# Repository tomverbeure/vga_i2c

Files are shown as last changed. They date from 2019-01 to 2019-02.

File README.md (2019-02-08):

# VGA I2C GPIO + Atari 2600 Joystick Extender

**A detailed write-up about this project can be found [here](https://tomverbeure.github.io/2019/02/05/VGA-I2C-My-First-PCB.html).**

The [Pano Logic G1](https://github.com/tomverbeure/panologic) doesn't have an easy
way to add GPIOs or non-USB input devices.

If you want to control a game like PacMan with a joystick, you need to be creative.
One way to do that is by soldering some wires to connect unused VGA pins to the
FPGA as demonstrated by the [Pano Man](https://github.com/skiphansen/pano_man) project.

But only allow for a lot of buttons. The Pano Man README suggested connecting a
GPIO I2C expander to the I2C wires of the VGA cable.

This project does exactly that!

It's a VGA to VGA feedthru board that taps the I2C wires, adds an I2C GPIO expander, connects it
to 2 Atari 2600 joystick ports, 4 additional switches and 2 LEDs.

I shared the schematics of this board with Skip, the author of Pano Man, and he made a
version that supports this board!

The design is very simple and it was the perfect project to learn KiCAD and design and 
send out for production my first PCB.

The schematic:

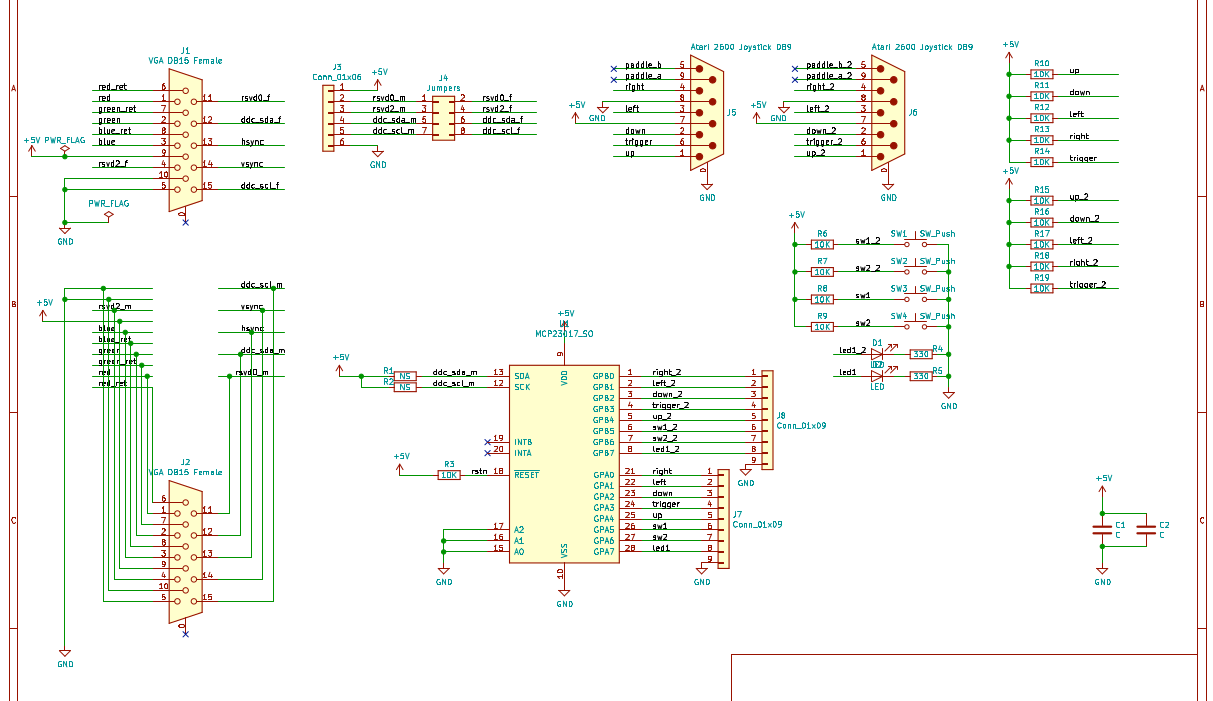
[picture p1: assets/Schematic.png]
Schematic


The PCB layout:

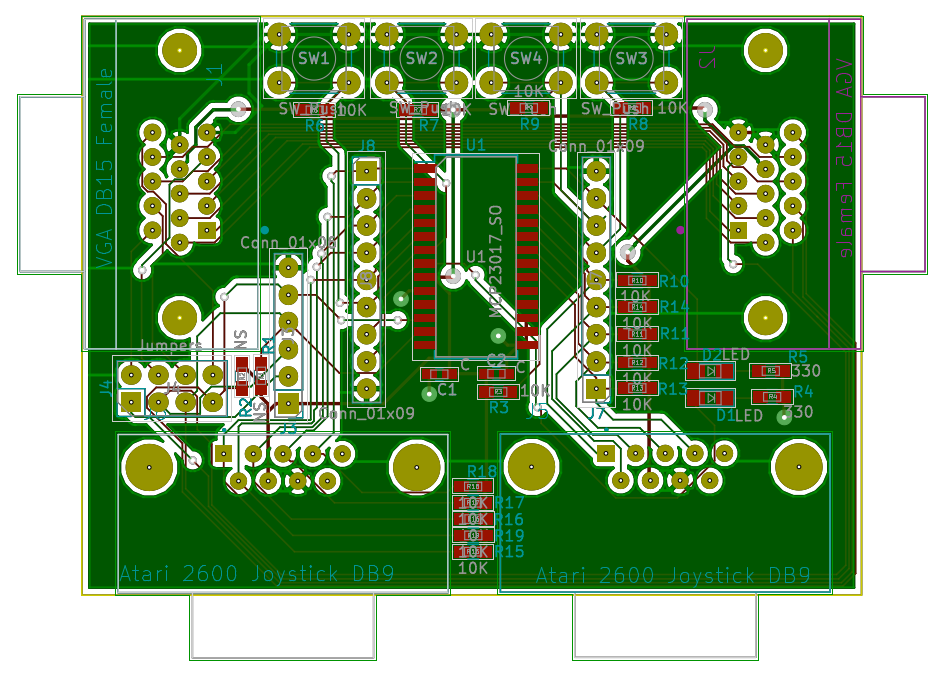
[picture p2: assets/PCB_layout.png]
PCB Layout


The result:

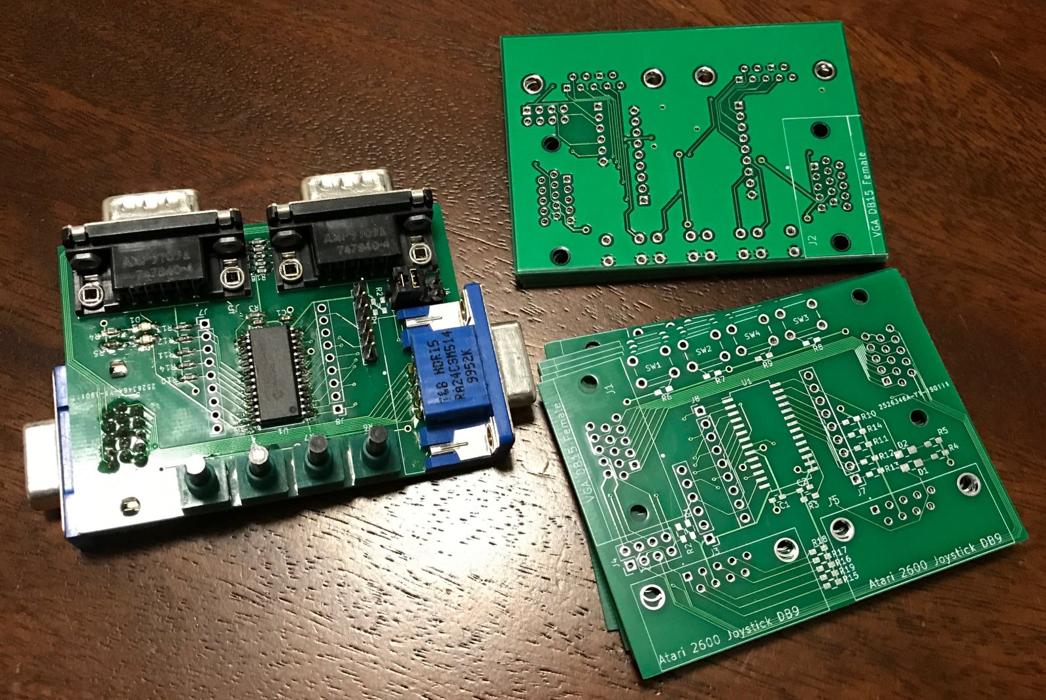
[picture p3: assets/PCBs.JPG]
PCBs


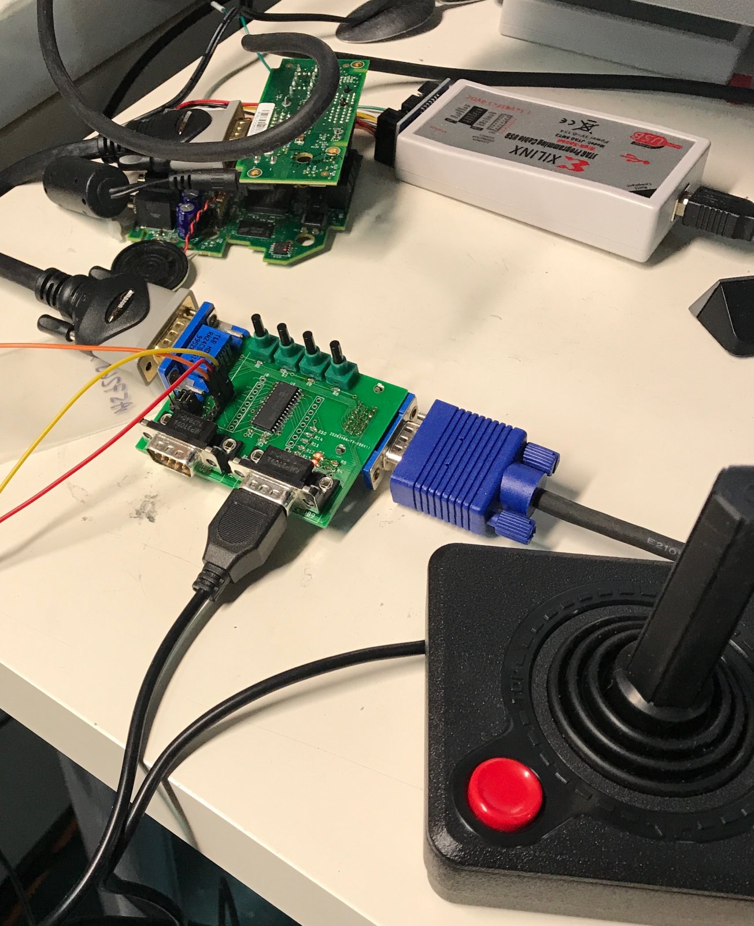
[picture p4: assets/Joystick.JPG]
Joystick


[Video](https://player.vimeo.com/video/315809161)

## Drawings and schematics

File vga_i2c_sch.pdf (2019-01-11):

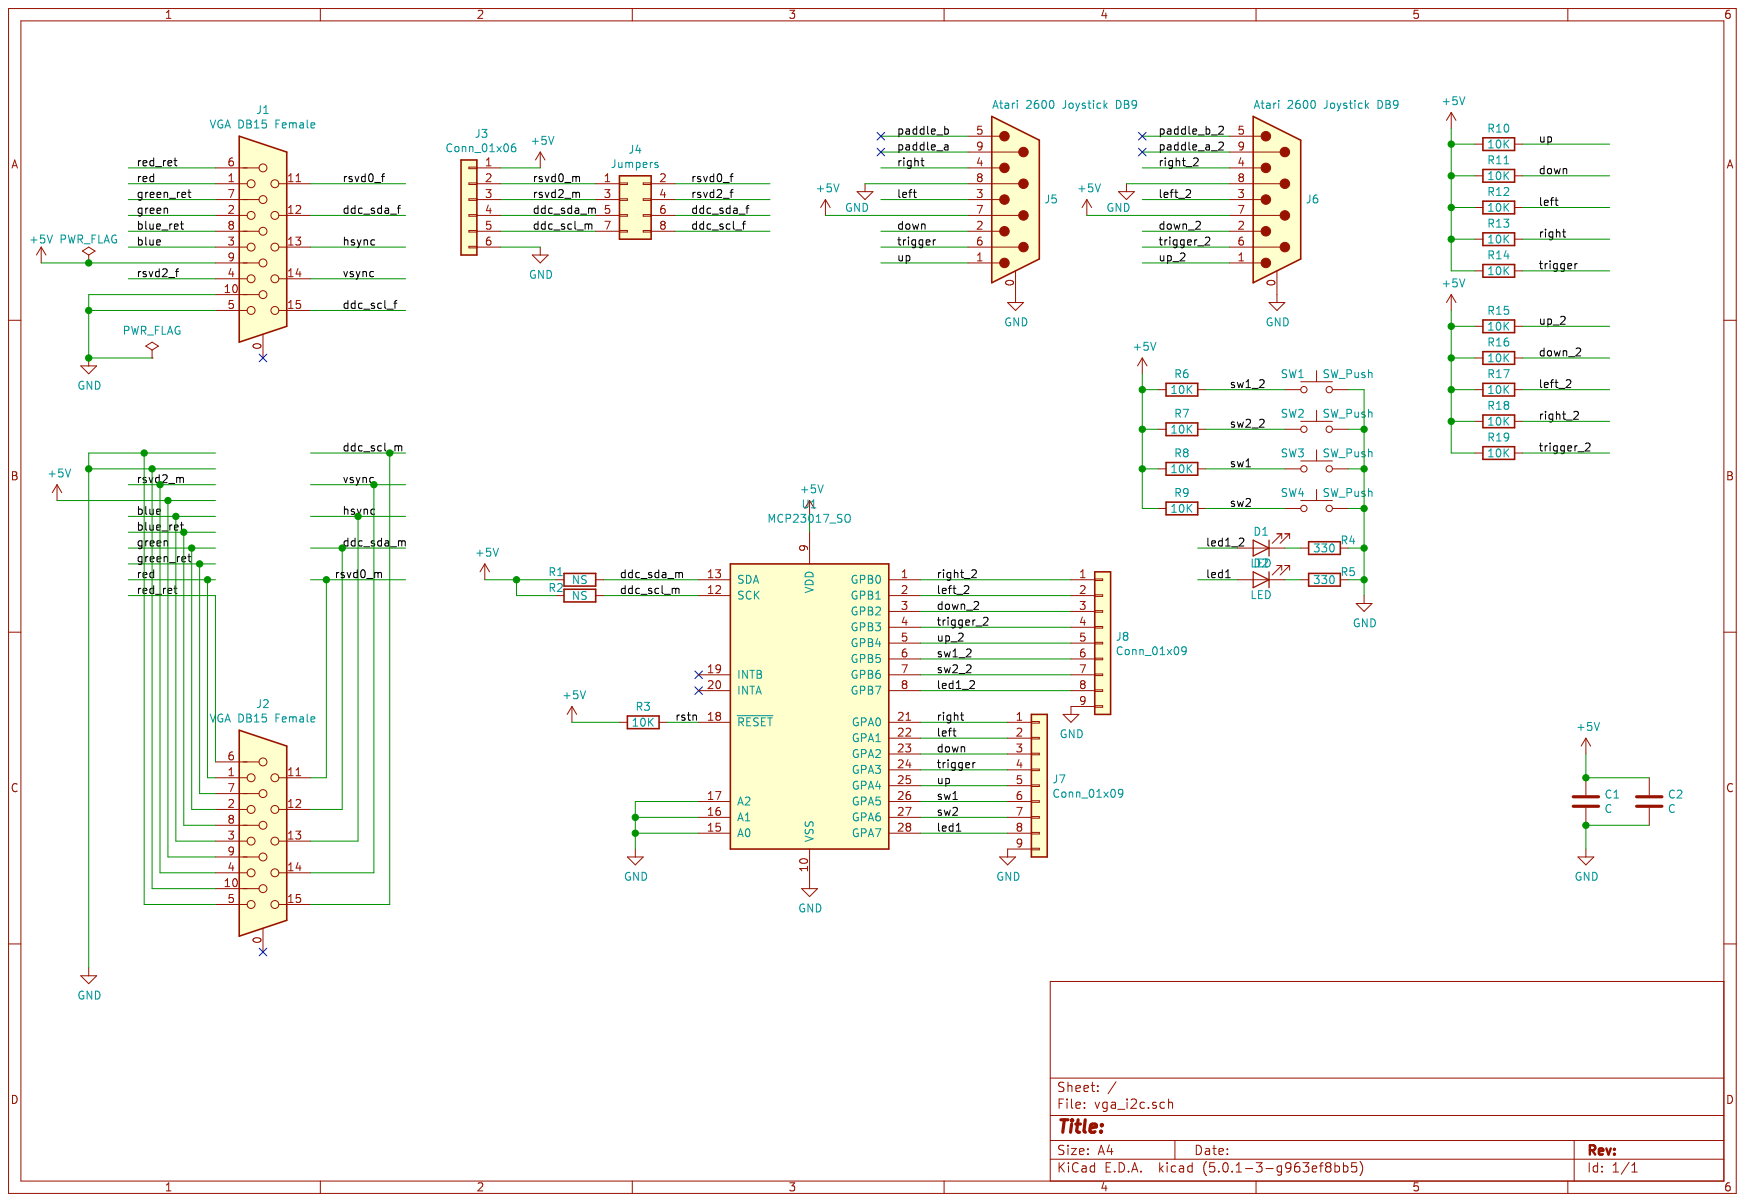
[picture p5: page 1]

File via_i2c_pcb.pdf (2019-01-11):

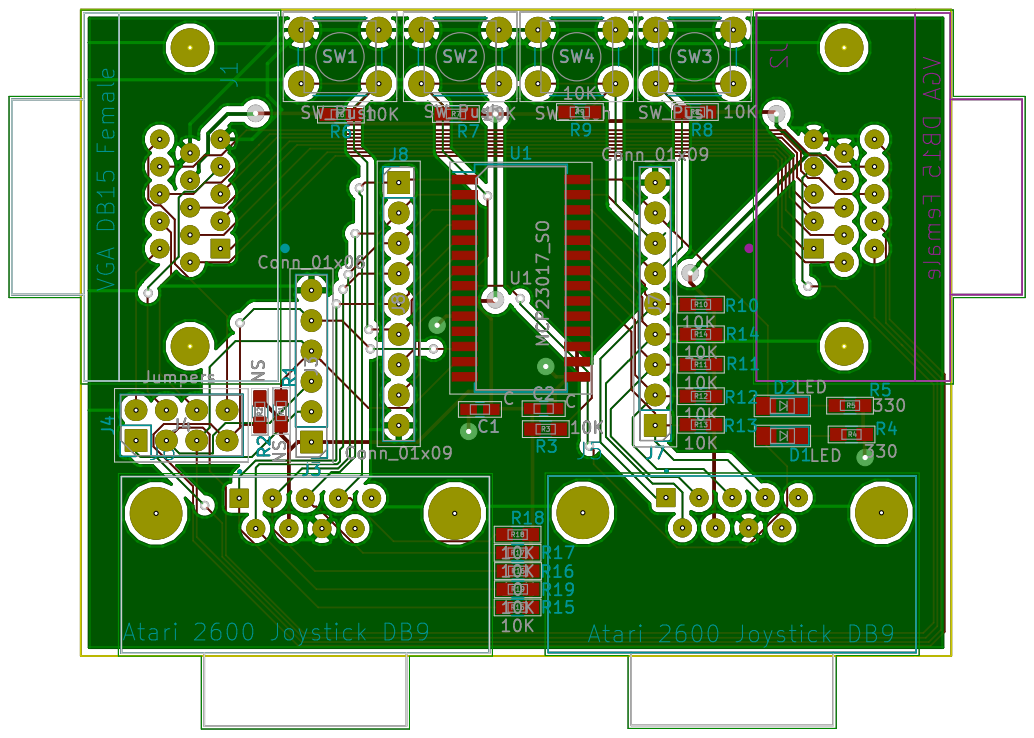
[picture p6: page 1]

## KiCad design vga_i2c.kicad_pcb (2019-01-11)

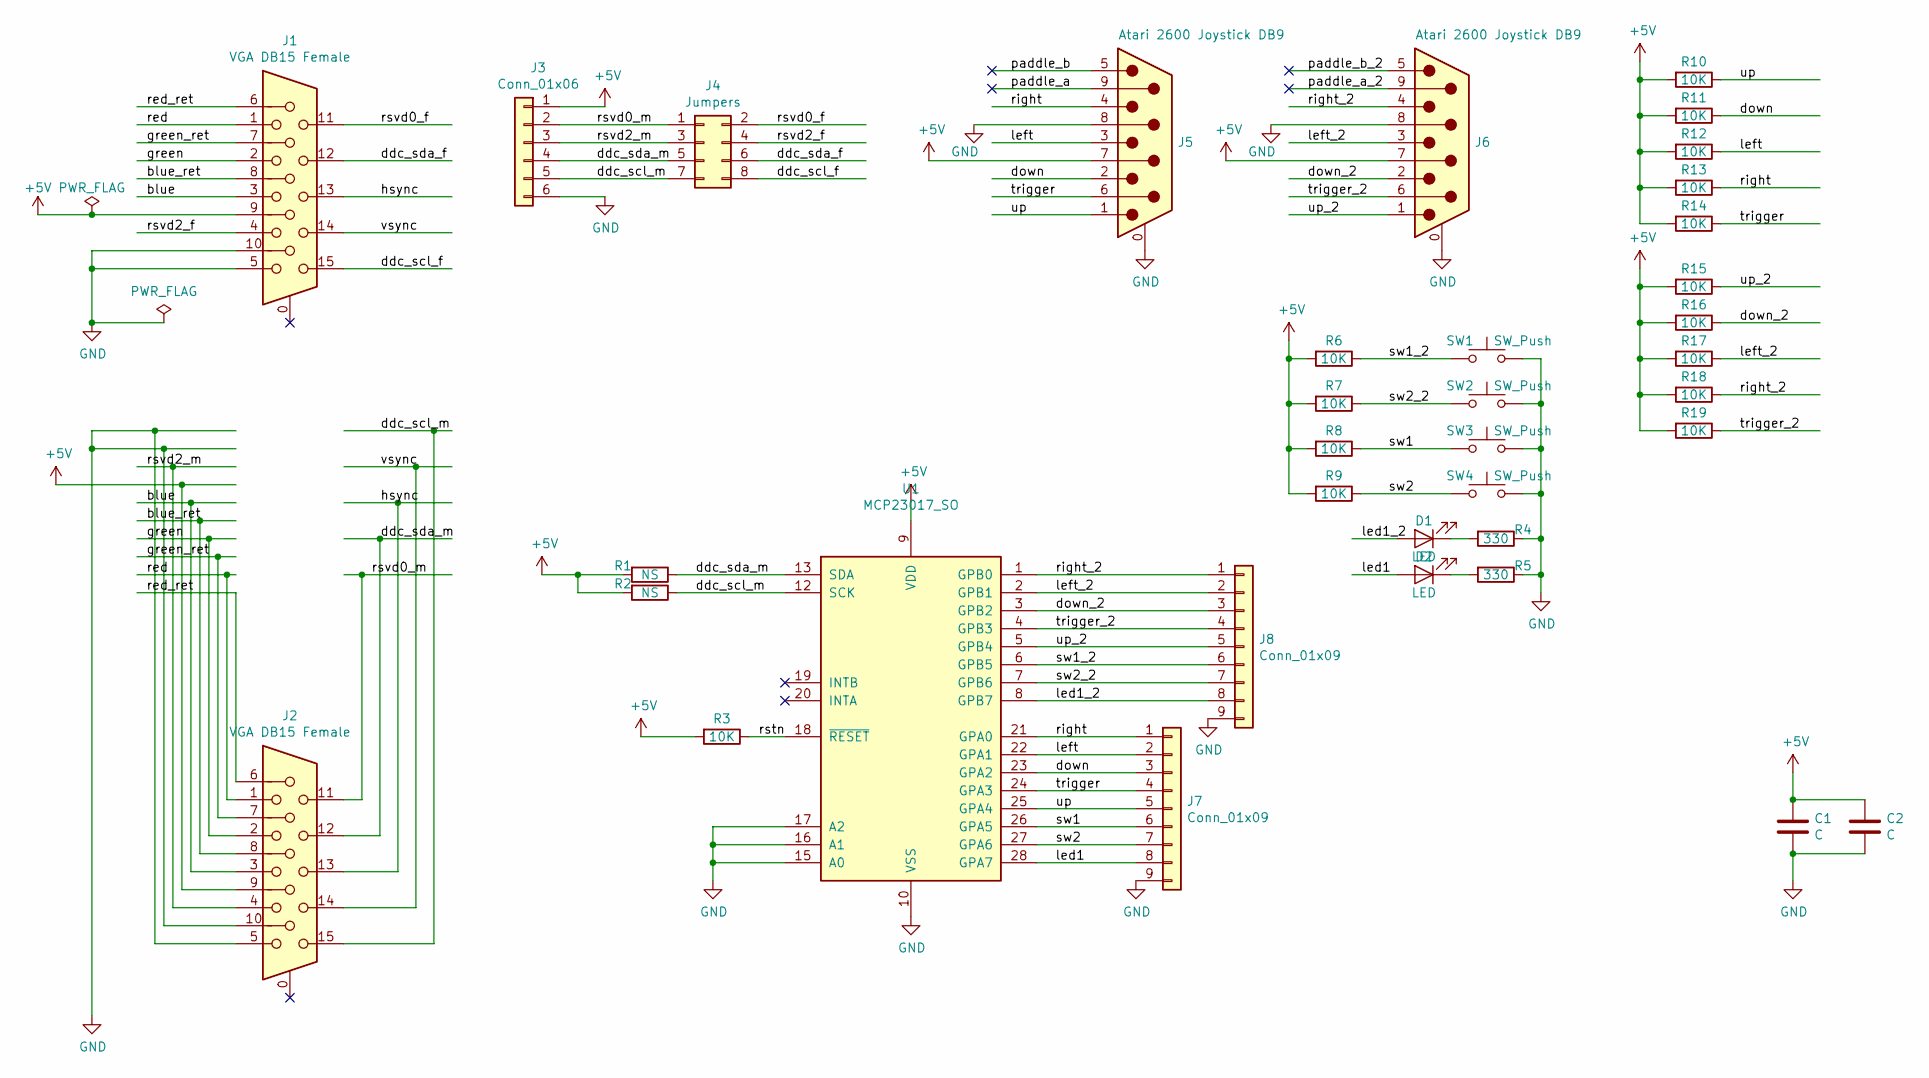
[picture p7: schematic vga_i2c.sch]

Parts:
C1, C2: C; C_0603_HandSoldering
D1, D2: LED; LED_0805_HandSoldering
J1, J2: VGA DB15 Female; NORCOMP_181-015-213R561
J3: Conn_01x06; Pin_Header_Straight_1x06_Pitch2.54mm
J4: Jumpers; Pin_Header_Straight_2x04_Pitch2.54mm
J5, J6: Atari 2600 Joystick DB9; TE_1-1634580-2
J7, J8: Conn_01x09; Pin_Header_Straight_1x09_Pitch2.54mm
R1, R2: NS; R_0603_HandSoldering
R3, R6, R7, R8, R9, R10, R11, R12, R13, R14, R15, R16, R17, R18, R19: 10K; R_0603_HandSoldering
R4, R5: 330; R_0603_HandSoldering
SW1, SW2, SW3, SW4: SW_Push; SW_PUSH_6mm
U1: MCP23017_SO; SOIC-28W_7.5x18.7mm_Pitch1.27mm

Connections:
+5V: C1.1, C2.1, J1.9, J2.9, J3.1, J5.7, J6.7, R1.2, R2.2, R3.2, R6.2, R7.2, R8.2, R9.2, R10.2, R11.2, R12.2, R13.2, R14.2, R15.2, R16.2, R17.2, R18.2, R19.2, U1.9 (VDD)
/blue: J1.3, J2.3
/blue_ret: J1.8, J2.8
/ddc_scl_f: J1.15, J4.8
/ddc_scl_m: J2.15, J3.5, J4.7, R2.1, U1.12 (SCK)
/ddc_sda_f: J1.12, J4.6
/ddc_sda_m: J2.12, J3.4, J4.5, R1.1, U1.13 (SDA)
/down: J5.2, J7.3, R11.1, U1.23 (GPA2)
/down_2: J6.2, J8.3, R16.1, U1.3 (GPB2)
/green: J1.2, J2.2
/green_ret: J1.7, J2.7
/hsync: J1.13, J2.13
/led1: D2.2 (A), J7.8, U1.28 (GPA7)
/led1_2: D1.2 (A), J8.8, U1.8 (GPB7)
/left: J5.3, J7.2, R12.1, U1.22 (GPA1)
/left_2: J6.3, J8.2, R17.1, U1.2 (GPB1)
/paddle_a: J5.9
/paddle_a_2: J6.9
/paddle_b: J5.5
/paddle_b_2: J6.5
/red: J1.1, J2.1
/red_ret: J1.6, J2.6
/right: J5.4, J7.1, R13.1, U1.21 (GPA0)
/right_2: J6.4, J8.1, R18.1, U1.1 (GPB0)
/rstn: R3.1, U1.18 (~RESET~)
/rsvd0_f: J1.11, J4.2
/rsvd0_m: J2.11, J3.2, J4.1
/rsvd2_f: J1.4, J4.4
/rsvd2_m: J2.4, J3.3, J4.3
/sw1: J7.6, R8.1, SW3.1, U1.26 (GPA5)
/sw1_2: J8.6, R6.1, SW1.1, U1.6 (GPB5)
/sw2: J7.7, R9.1, SW4.1, U1.27 (GPA6)
/sw2_2: J8.7, R7.1, SW2.1, U1.7 (GPB6)
/trigger: J5.6, J7.4, R14.1, U1.24 (GPA3)
/trigger_2: J6.6, J8.4, R19.1, U1.4 (GPB3)
/up: J5.1, J7.5, R10.1, U1.25 (GPA4)
/up_2: J6.1, J8.5, R15.1, U1.5 (GPB4)
/vsync: J1.14, J2.14
GND: C1.2, C2.2, J1.5, J1.10, J2.5, J2.10, J3.6, J5.0 (PAD), J5.8, J6.0 (PAD), J6.8, J7.9, J8.9, R4.1, R5.1, SW1.2, SW2.2, SW3.2, SW4.2, U1.10 (VSS), U1.15 (A0), U1.16 (A1), U1.17 (A2)
unnamed: D1.1 (K), R4.2
unnamed: D2.1 (K), R5.2

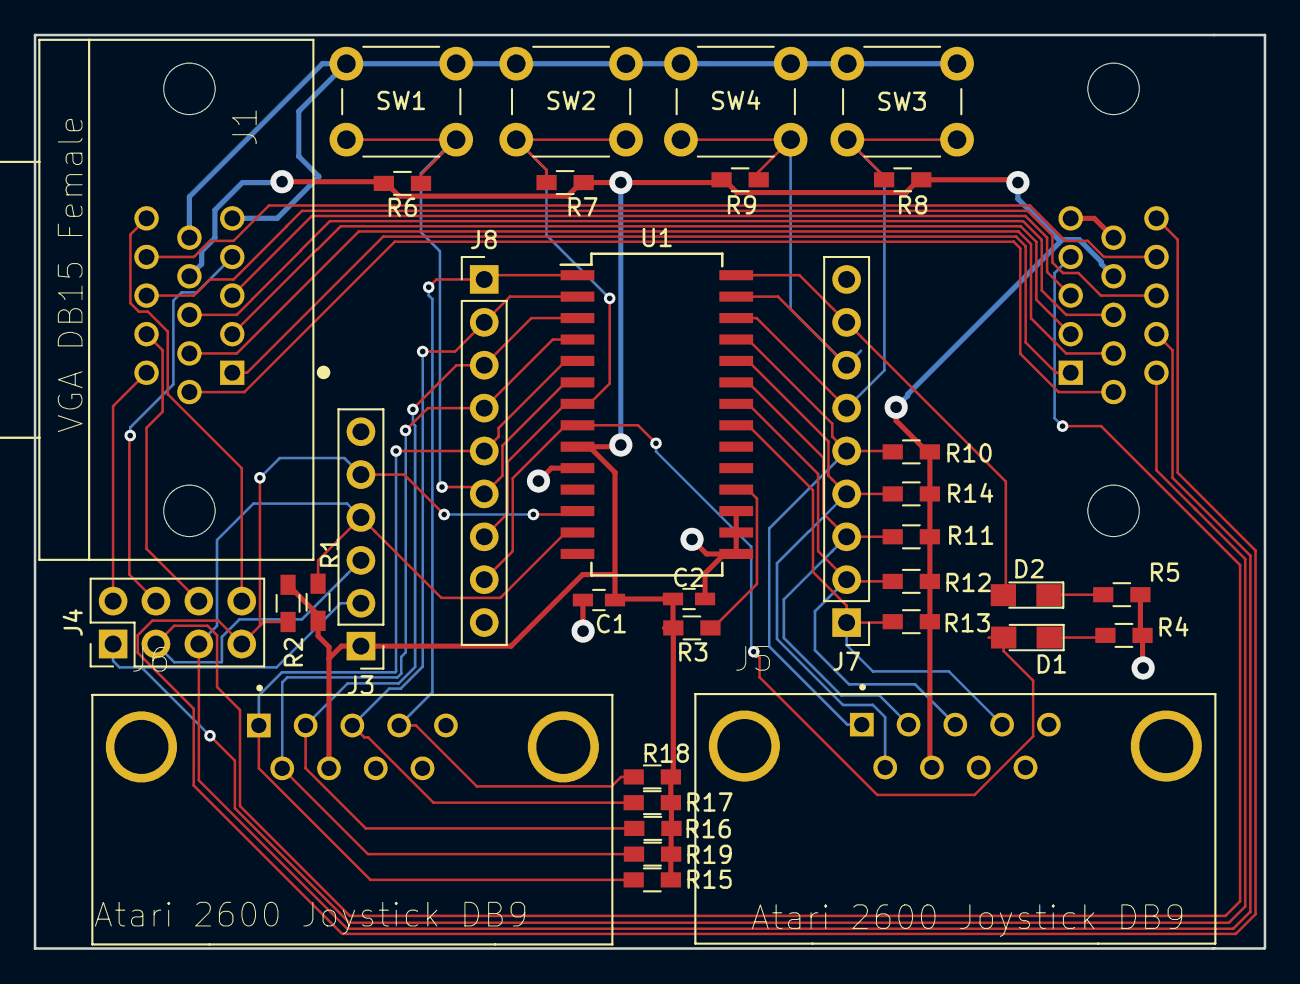
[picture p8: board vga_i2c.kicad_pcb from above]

Board: 2 copper layers, 72.8 x 54.1 mm, 36 parts (1 on the bottom side), 37 nets.

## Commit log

2019-01-09 Schematic rev 1 ready.
    [vga_i2c.kicad_pcb, vga_i2c.sch]
2019-01-10 Version 1
    [vga_i2c.sch]
2019-01-10 !st production version.
    [vga_i2c.kicad_pcb, vga_i2c.sch]
2019-01-10 PDF of schematic and pcb
2019-01-11 Version with 2 joysticks.
    [vga_i2c-B.Cu.gbr, vga_i2c-B.Mask.gbr, vga_i2c-B.SilkS.gbr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]
